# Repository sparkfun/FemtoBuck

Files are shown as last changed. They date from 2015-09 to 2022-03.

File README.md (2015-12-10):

FemtoBuck LED Driver
===================  
FemtoBuck LED Driver](https://cdn.sparkfun.com/assets/parts/1/1/2/1/0/13716-01.jpg) 
 
[*FemtoBuck LED Driver (COM-13716)*](https://www.sparkfun.com/products/13716) 

This breakout board allows you to dim a single high-power channel of LEDs from 0-330mA, or 0-660mA (depending on the setting of a solder jumper), at up to 36V. 
Dimming control can be either via PWM or via analog signal from 0-2.5V.

Repository Contents
-------------------
* **/Hardware** - All Eagle design files (.brd, .sch)
* **/Production** - Test bed files and production panel files

Documentation
--------------
* **[Hookup Guide](https://learn.sparkfun.com/tutorials/femtobuck-constant-current-led-driver-hookup-guide)** - Basic hookup guide for the FemtoBuck.
* **[SparkFun Fritzing repo](https://github.com/sparkfun/Fritzing_Parts)** - Fritzing diagrams for SparkFun products.
* **[SparkFun 3D Model repo](https://github.com/sparkfun/3D_Models)** - 3D models of SparkFun products. 

Product Versions
----------------
* [COM-13716](https://www.sparkfun.com/products/13716)- Version 1.2. Currently for sale. 
* [COM-12937] (https://www.sparkfun.com/products/12937)- Version 1.0. Retired. 

Version History
---------------
* [V_1.2](https://github.com/sparkfun/FemtoBuck/tree/V_1.2) - GitHub files for version 1.2. 
* [V_1.0](https://github.com/sparkfun/FemtoBuck/tree/v_10) - GitHub files for version 1.0. 

License Information
-------------------

This product is _**open source**_! 

Please review the LICENSE.md file for license information. 

If you have any questions or concerns on licensing, please contact techsupport@sparkfun.com.

Distributed as-is; no warranty is given.

- Your friends at SparkFun.

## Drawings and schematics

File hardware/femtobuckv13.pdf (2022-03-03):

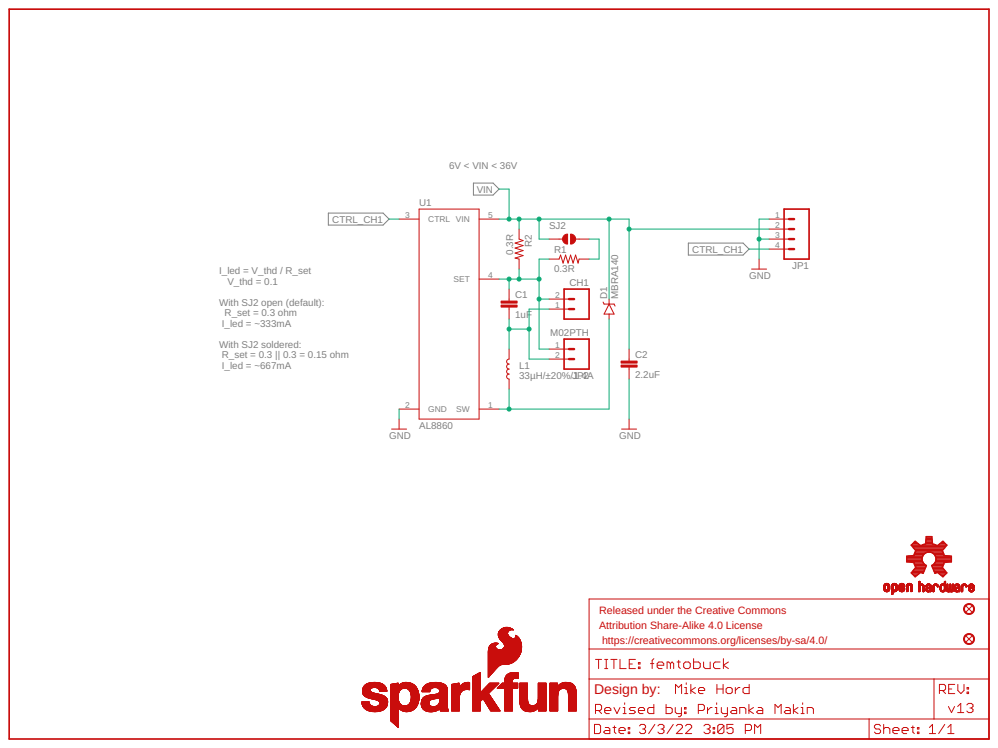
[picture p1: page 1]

Released under the Creative Commons Attribution Share-Alike 4.0 License

https://creativecommons.org/licenses/by-sa/4.0/

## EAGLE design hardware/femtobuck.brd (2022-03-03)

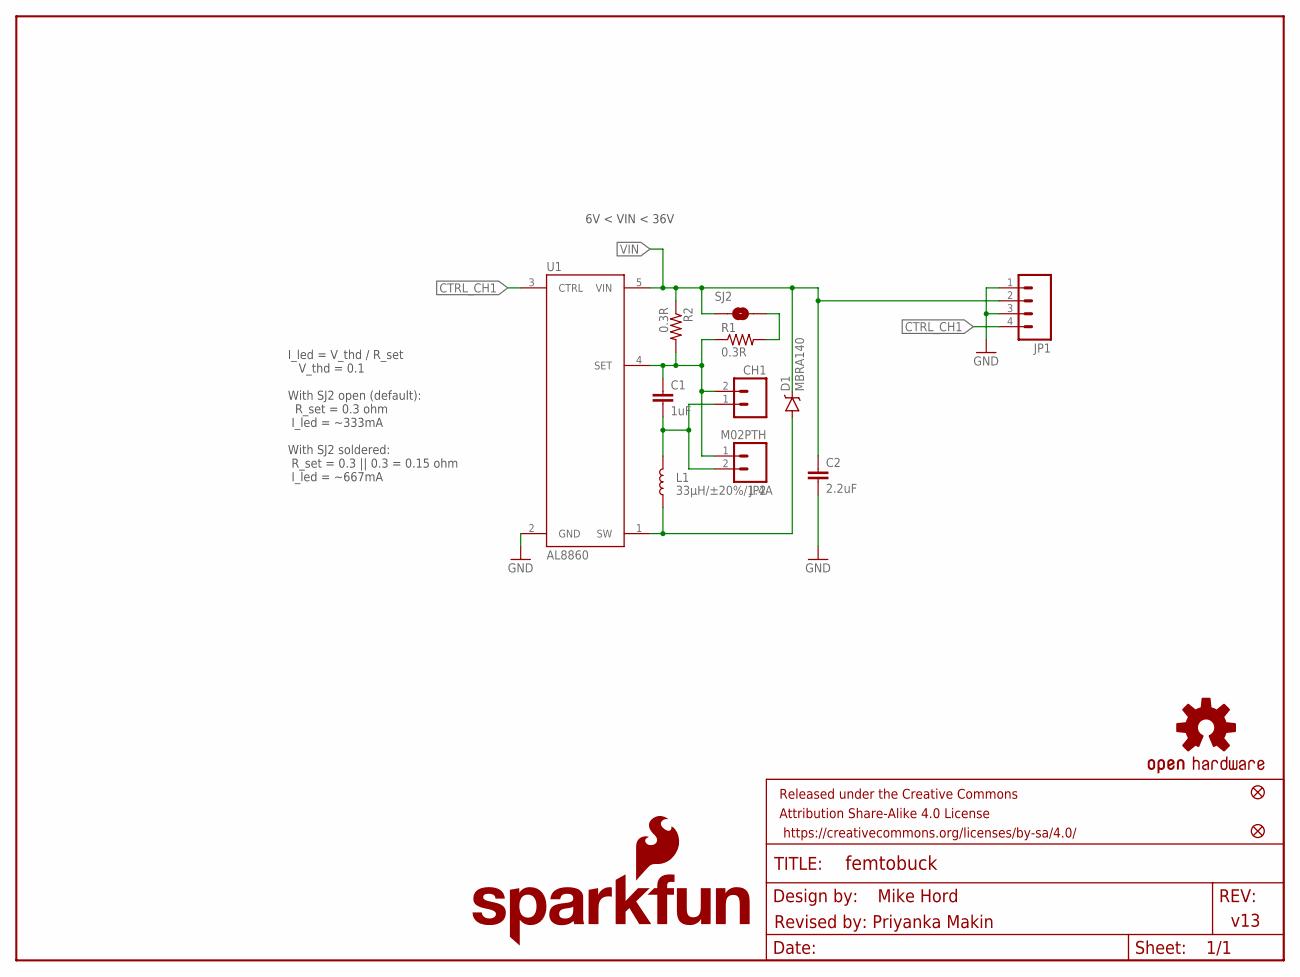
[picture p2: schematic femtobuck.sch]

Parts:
C1: 1uF; 1206-CAP
C2: 2.2uF; 1206-CAP
CH1: CONN_023.5MM_LOCK; SCREWTERMINAL-3.5MM-2_LOCK
D1: MBRA140; SMA-DIODE
FID1, FID2: FIDUCIAL1X2; FIDUCIAL-1X2
FRAME1: FRAME-LETTER; CREATIVE_COMMONS
JP1: M04PTH; 1X04
JP2: M02PTH; 1X02@1
L1: 33µH/±20%/1.4A; SRN6045
LOGO1: OSHW-LOGOS; OSHW-LOGO-S
LOGO2: SFE_LOGO_NAME_FLAME.1_INCH; SFE_LOGO_NAME_FLAME_.1
R1, R2: 0.3R; 0805
SJ2: NO Jumper; SMT-JUMPER_2_NO_NO-SILK
U1: AL8860; SOT23-5

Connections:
CTRL_CH1: JP1.4, U1.3 (CTRL)
GND: C2.2, JP1.1, JP1.3, U1.2 (GND)
unnamed: R1.2, SJ2.2
OUT+: C1.1, CH1.2, JP2.1, R1.1, R2.2, U1.4 (SET)
OUT-: C1.2, CH1.1, JP2.2, L1.2
SW: D1.A, L1.1, U1.1 (SW)
VIN: C2.1, D1.C, JP1.2, R2.1, SJ2.1, U1.5 (VIN)

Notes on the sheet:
I_led = V_thd / R_set V_thd = 0.1 With SJ2 open (default): R_set = 0.3 ohm I_led = ~333mA With SJ2 soldered: R_set = 0.3 || 0.3 = 0.15 ohm I_led = ~667mA
v13
Mike Hord
6V < VIN < 36V
Revised by: Priyanka Makin

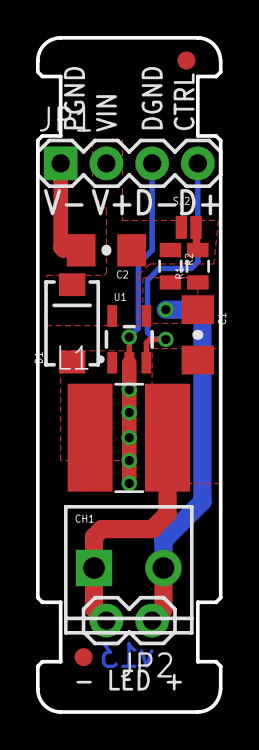
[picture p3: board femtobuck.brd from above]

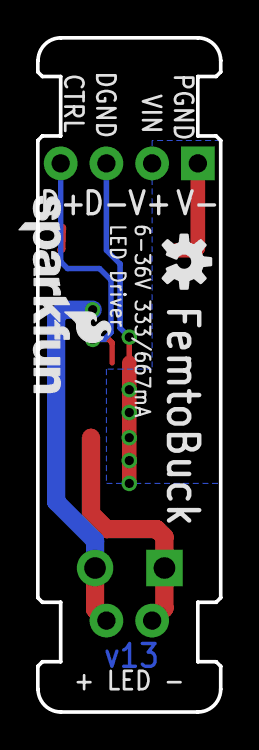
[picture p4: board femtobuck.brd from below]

Board: 2 copper layers, 10.2 x 37.5 mm, 16 parts (2 on the bottom side), 7 nets.

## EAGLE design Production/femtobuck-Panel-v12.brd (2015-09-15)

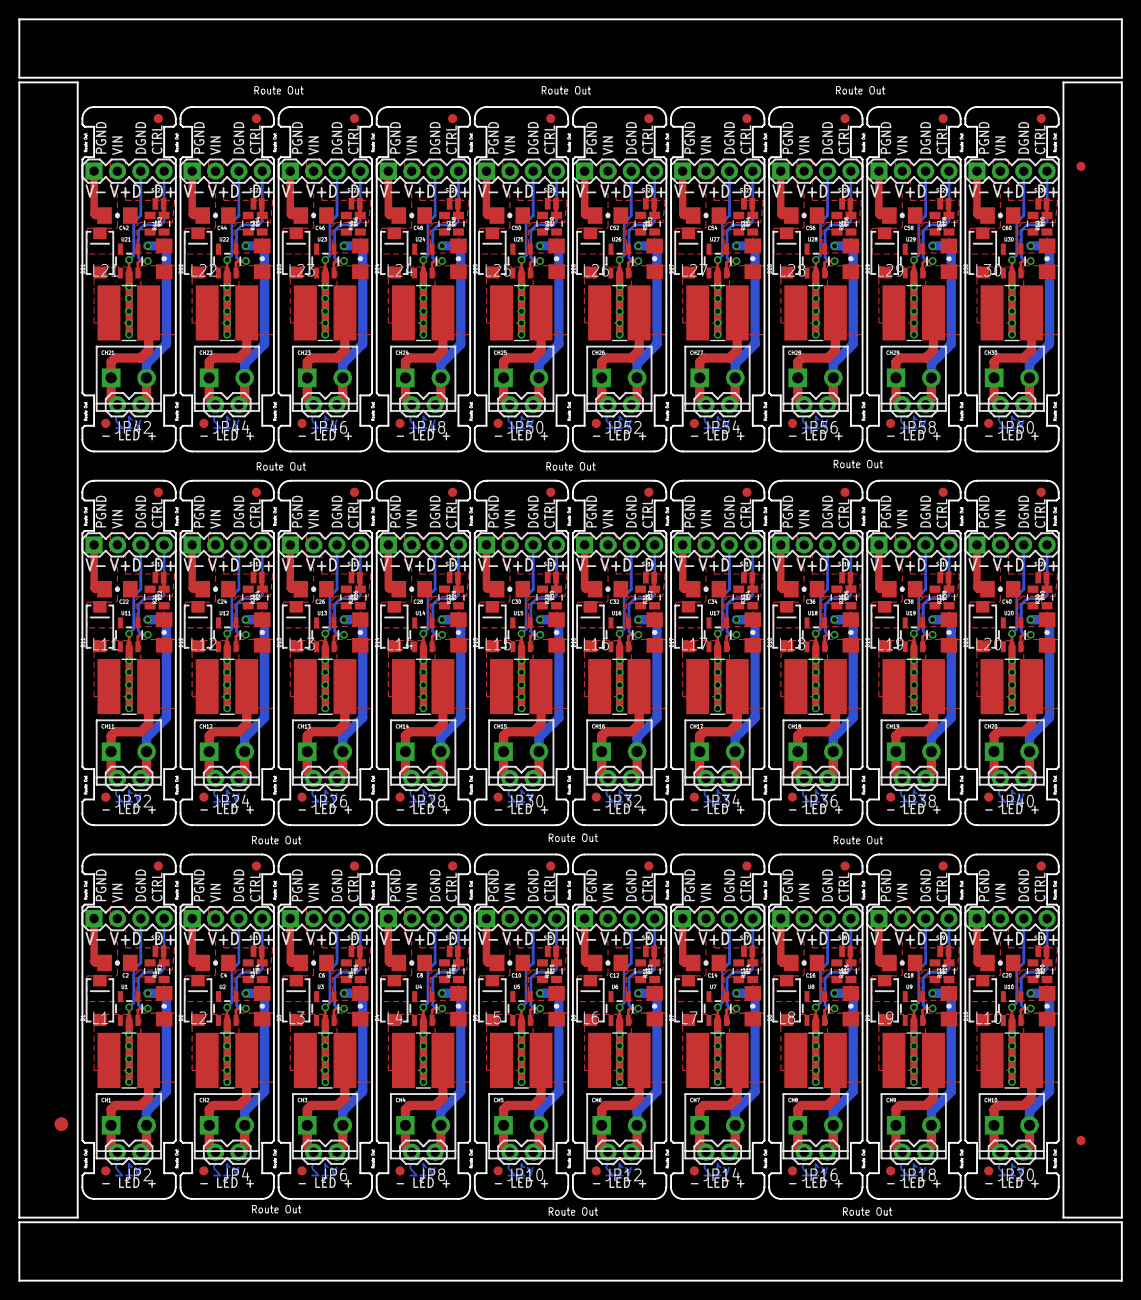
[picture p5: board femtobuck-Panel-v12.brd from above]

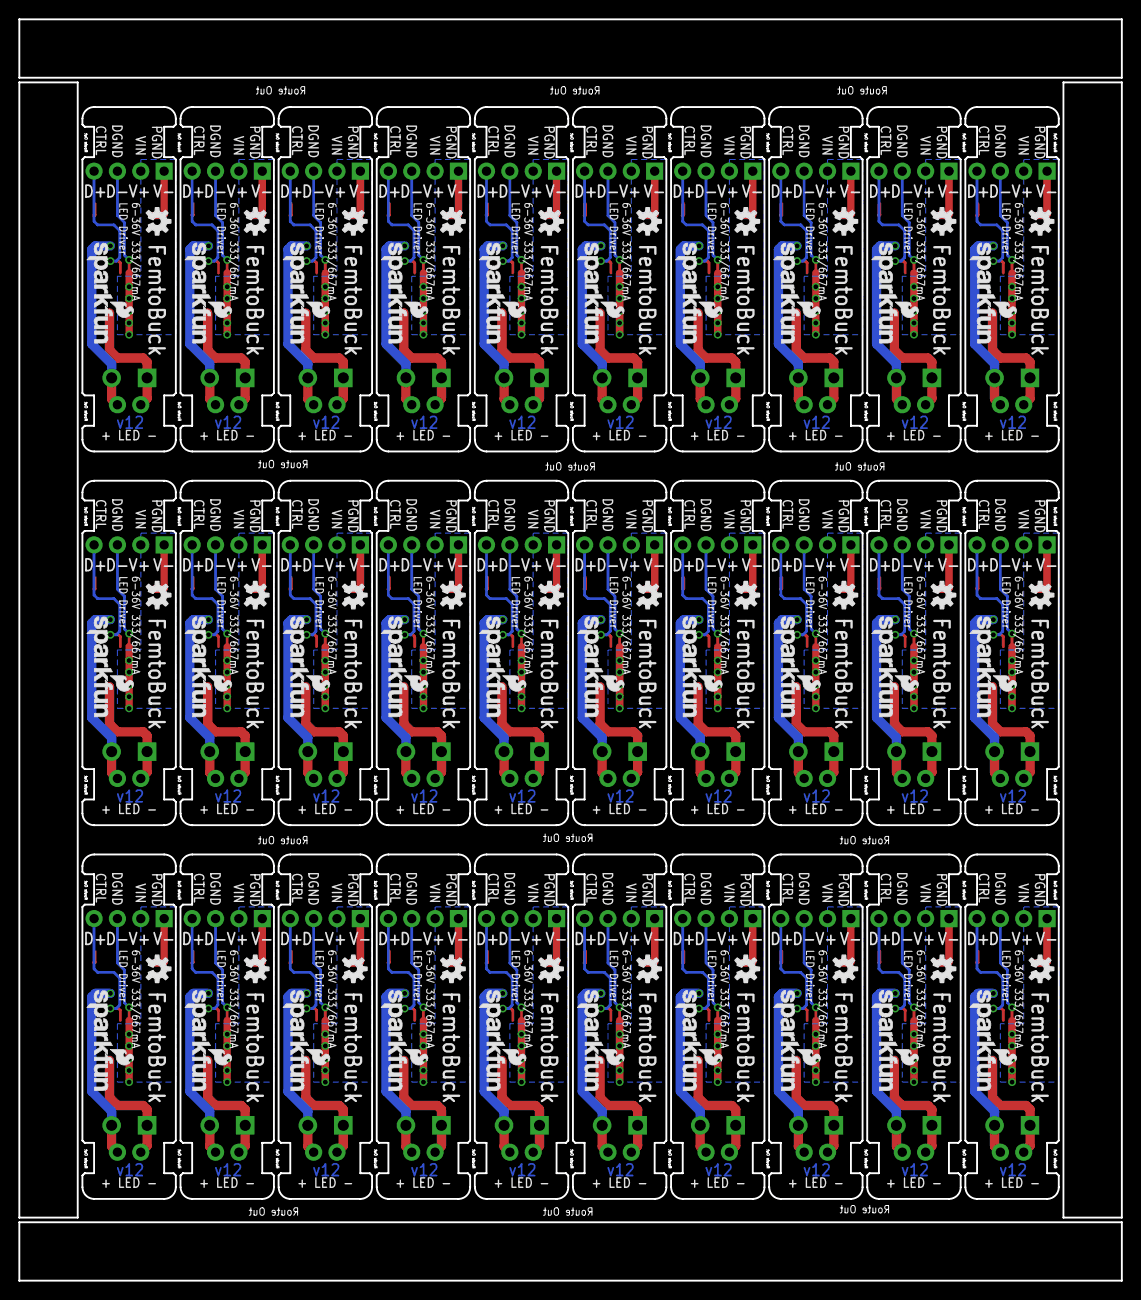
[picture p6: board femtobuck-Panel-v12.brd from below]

Board: 2 copper layers, 119.9 x 137.2 mm, 453 parts (60 on the bottom side), 210 nets.

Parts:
C1, C3, C5, C7, C9, C11, C13, C15, C17, C19, C21, C23, C25, C27, C29, C31, C33, C35, C37, C39, C41, C43, C45, C47, C49, C51, C53, C55, C57, C59: 1uF; 1206-CAP
C2, C4, C6, C8, C10, C12, C14, C16, C18, C20, C22, C24, C26, C28, C30, C32, C34, C36, C38, C40, C42, C44, C46, C48, C50, C52, C54, C56, C58, C60: 2.2uF; 1206-CAP
CH1, CH2, CH3, CH4, CH5, CH6, CH7, CH8, CH9, CH10, CH11, CH12, CH13, CH14, CH15, CH16, CH17, CH18, CH19, CH20, CH21, CH22, CH23, CH24, CH25, CH26, CH27, CH28, CH29, CH30: SCREWTERMINAL-3.5MM-2_LOCK
D1, D2, D3, D4, D5, D6, D7, D8, D9, D10, D11, D12, D13, D14, D15, D16, D17, D18, D19, D20, D21, D22, D23, D24, D25, D26, D27, D28, D29, D30: MBRA140; SMA-DIODE
E$1: FIDUCIAL-1.5X3
E$2, E$5: FIDUCIAL-1X2
FID1, FID2, FID3, FID4, FID5, FID6, FID7, FID8, FID9, FID10, FID11, FID12, FID13, FID14, FID15, FID16, FID17, FID18, FID19, FID20, FID21, FID22, FID23, FID24, FID25, FID26, FID27, FID28, FID29, FID30, FID31, FID32, FID33, FID34, FID35, FID36, FID37, FID38, FID39, FID40, FID41, FID42, FID43, FID44, FID45, FID46, FID47, FID48, FID49, FID50, FID51, FID52, FID53, FID54, FID55, FID56, FID57, FID58, FID59, FID60: FIDUCIAL1X2; FIDUCIAL-1X2
JP1, JP3, JP5, JP7, JP9, JP11, JP13, JP15, JP17, JP19, JP21, JP23, JP25, JP27, JP29, JP31, JP33, JP35, JP37, JP39, JP41, JP43, JP45, JP47, JP49, JP51, JP53, JP55, JP57, JP59: 1X04
JP2, JP4, JP6, JP8, JP10, JP12, JP14, JP16, JP18, JP20, JP22, JP24, JP26, JP28, JP30, JP32, JP34, JP36, JP38, JP40, JP42, JP44, JP46, JP48, JP50, JP52, JP54, JP56, JP58, JP60: M02PTH; 1X02
L1, L2, L3, L4, L5, L6, L7, L8, L9, L10, L11, L12, L13, L14, L15, L16, L17, L18, L19, L20, L21, L22, L23, L24, L25, L26, L27, L28, L29, L30: 33uH; SRN6045
LOGO1, LOGO3, LOGO5, LOGO7, LOGO9, LOGO11, LOGO13, LOGO15, LOGO17, LOGO19, LOGO21, LOGO23, LOGO25, LOGO27, LOGO29, LOGO31, LOGO33, LOGO35, LOGO37, LOGO39, LOGO41, LOGO43, LOGO45, LOGO47, LOGO49, LOGO51, LOGO53, LOGO55, LOGO57, LOGO59: OSHW-LOGOS; OSHW-LOGO-S
LOGO2, LOGO4, LOGO6, LOGO8, LOGO10, LOGO12, LOGO14, LOGO16, LOGO18, LOGO20, LOGO22, LOGO24, LOGO26, LOGO28, LOGO30, LOGO32, LOGO34, LOGO36, LOGO38, LOGO40, LOGO42, LOGO44, LOGO46, LOGO48, LOGO50, LOGO52, LOGO54, LOGO56, LOGO58, LOGO60: SFE_LOGO_NAME_FLAME.1_INCH; SFE_LOGO_NAME_FLAME_.1
R1, R2, R3, R4, R5, R6, R7, R8, R9, R10, R11, R12, R13, R14, R15, R16, R17, R18, R19, R20, R21, R22, R23, R24, R25, R26, R27, R28, R29, R30, R31, R32, R33, R34, R35, R36, R37, R38, R39, R40, R41, R42, R43, R44, R45, R46, R47, R48, R49, R50, R51, R52, R53, R54, R55, R56, R57, R58, R59, R60: 0.3R; 0805
SJ1, SJ2, SJ3, SJ4, SJ5, SJ6, SJ7, SJ8, SJ9, SJ10, SJ11, SJ12, SJ13, SJ14, SJ15, SJ16, SJ17, SJ18, SJ19, SJ20, SJ21, SJ22, SJ23, SJ24, SJ25, SJ26, SJ27, SJ28, SJ29, SJ30: NO Jumper; PAD-JUMPER-2-NO_NO_SILK
U1, U2, U3, U4, U5, U6, U7, U8, U9, U10, U11, U12, U13, U14, U15, U16, U17, U18, U19, U20, U21, U22, U23, U24, U25, U26, U27, U28, U29, U30: AL8805; SOT23-5

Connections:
CTRL_CH1: JP1.4, U1.3
CTRL_CH2: JP3.4, U2.3
CTRL_CH3: JP5.4, U3.3
CTRL_CH4: JP7.4, U4.3
CTRL_CH5: JP9.4, U5.3
CTRL_CH6: JP11.4, U6.3
CTRL_CH7: JP13.4, U7.3
CTRL_CH8: JP15.4, U8.3
CTRL_CH9: JP17.4, U9.3
CTRL_CH10: JP19.4, U10.3
CTRL_CH11: JP21.4, U11.3
CTRL_CH12: JP23.4, U12.3
CTRL_CH13: JP25.4, U13.3
CTRL_CH14: JP27.4, U14.3
CTRL_CH15: JP29.4, U15.3
CTRL_CH16: JP31.4, U16.3
CTRL_CH17: JP33.4, U17.3
CTRL_CH18: JP35.4, U18.3
CTRL_CH19: JP37.4, U19.3
CTRL_CH20: JP39.4, U20.3
CTRL_CH21: JP41.4, U21.3
CTRL_CH22: JP43.4, U22.3
CTRL_CH23: JP45.4, U23.3
CTRL_CH24: JP47.4, U24.3
CTRL_CH25: JP49.4, U25.3
CTRL_CH26: JP51.4, U26.3
CTRL_CH27: JP53.4, U27.3
CTRL_CH28: JP55.4, U28.3
CTRL_CH29: JP57.4, U29.3
CTRL_CH30: JP59.4, U30.3
GND: C2.2, JP1.1, JP1.3, U1.2
GND1: C4.2, JP3.1, JP3.3, U2.2
GND2: C6.2, JP5.1, JP5.3, U3.2
GND3: C8.2, JP7.1, JP7.3, U4.2
GND4: C10.2, JP9.1, JP9.3, U5.2
GND5: C12.2, JP11.1, JP11.3, U6.2
GND6: C14.2, JP13.1, JP13.3, U7.2
GND7: C16.2, JP15.1, JP15.3, U8.2
GND8: C18.2, JP17.1, JP17.3, U9.2
GND9: C20.2, JP19.1, JP19.3, U10.2
GND10: C22.2, JP21.1, JP21.3, U11.2
GND11: C24.2, JP23.1, JP23.3, U12.2
GND12: C26.2, JP25.1, JP25.3, U13.2
GND13: C28.2, JP27.1, JP27.3, U14.2
GND14: C30.2, JP29.1, JP29.3, U15.2
GND15: C32.2, JP31.1, JP31.3, U16.2
GND16: C34.2, JP33.1, JP33.3, U17.2
GND17: C36.2, JP35.1, JP35.3, U18.2
GND18: C38.2, JP37.1, JP37.3, U19.2
GND19: C40.2, JP39.1, JP39.3, U20.2
GND20: C42.2, JP41.1, JP41.3, U21.2
GND21: C44.2, JP43.1, JP43.3, U22.2
GND22: C46.2, JP45.1, JP45.3, U23.2
GND23: C48.2, JP47.1, JP47.3, U24.2
GND24: C50.2, JP49.1, JP49.3, U25.2
GND25: C52.2, JP51.1, JP51.3, U26.2
GND26: C54.2, JP53.1, JP53.3, U27.2
GND27: C56.2, JP55.1, JP55.3, U28.2
GND28: C58.2, JP57.1, JP57.3, U29.2
GND29: C60.2, JP59.1, JP59.3, U30.2
unnamed: R1.2, SJ2.2
unnamed: R3.2, SJ1.2
unnamed: R5.2, SJ3.2
unnamed: R7.2, SJ4.2
unnamed: R9.2, SJ5.2
unnamed: R11.2, SJ6.2
unnamed: R13.2, SJ7.2
unnamed: R15.2, SJ8.2
unnamed: R17.2, SJ9.2
unnamed: R19.2, SJ10.2
unnamed: R21.2, SJ11.2
unnamed: R23.2, SJ12.2
unnamed: R25.2, SJ13.2
unnamed: R27.2, SJ14.2
unnamed: R29.2, SJ15.2
unnamed: R31.2, SJ16.2
unnamed: R33.2, SJ17.2
unnamed: R35.2, SJ18.2
unnamed: R37.2, SJ19.2
unnamed: R39.2, SJ20.2
unnamed: R41.2, SJ21.2
unnamed: R43.2, SJ22.2
unnamed: R45.2, SJ23.2
unnamed: R47.2, SJ24.2
unnamed: R49.2, SJ25.2
unnamed: R51.2, SJ26.2
unnamed: R53.2, SJ27.2
unnamed: R55.2, SJ28.2
unnamed: R57.2, SJ29.2
unnamed: R59.2, SJ30.2
OUT+: C1.1, CH1.2, JP2.1, R1.1, R2.2, U1.4
OUT+1: C3.1, CH2.2, JP4.1, R3.1, R4.2, U2.4
OUT+2: C5.1, CH3.2, JP6.1, R5.1, R6.2, U3.4
OUT+3: C7.1, CH4.2, JP8.1, R7.1, R8.2, U4.4
OUT+4: C9.1, CH5.2, JP10.1, R9.1, R10.2, U5.4
OUT+5: C11.1, CH6.2, JP12.1, R11.1, R12.2, U6.4
OUT+6: C13.1, CH7.2, JP14.1, R13.1, R14.2, U7.4
OUT+7: C15.1, CH8.2, JP16.1, R15.1, R16.2, U8.4
OUT+8: C17.1, CH9.2, JP18.1, R17.1, R18.2, U9.4
OUT+9: C19.1, CH10.2, JP20.1, R19.1, R20.2, U10.4
OUT+10: C21.1, CH11.2, JP22.1, R21.1, R22.2, U11.4
OUT+11: C23.1, CH12.2, JP24.1, R23.1, R24.2, U12.4
OUT+12: C25.1, CH13.2, JP26.1, R25.1, R26.2, U13.4
OUT+13: C27.1, CH14.2, JP28.1, R27.1, R28.2, U14.4
OUT+14: C29.1, CH15.2, JP30.1, R29.1, R30.2, U15.4
OUT+15: C31.1, CH16.2, JP32.1, R31.1, R32.2, U16.4
OUT+16: C33.1, CH17.2, JP34.1, R33.1, R34.2, U17.4
OUT+17: C35.1, CH18.2, JP36.1, R35.1, R36.2, U18.4
OUT+18: C37.1, CH19.2, JP38.1, R37.1, R38.2, U19.4
OUT+19: C39.1, CH20.2, JP40.1, R39.1, R40.2, U20.4
OUT+20: C41.1, CH21.2, JP42.1, R41.1, R42.2, U21.4
OUT+21: C43.1, CH22.2, JP44.1, R43.1, R44.2, U22.4
OUT+22: C45.1, CH23.2, JP46.1, R45.1, R46.2, U23.4
OUT+23: C47.1, CH24.2, JP48.1, R47.1, R48.2, U24.4
OUT+24: C49.1, CH25.2, JP50.1, R49.1, R50.2, U25.4
OUT+25: C51.1, CH26.2, JP52.1, R51.1, R52.2, U26.4
OUT+26: C53.1, CH27.2, JP54.1, R53.1, R54.2, U27.4
OUT+27: C55.1, CH28.2, JP56.1, R55.1, R56.2, U28.4
OUT+28: C57.1, CH29.2, JP58.1, R57.1, R58.2, U29.4
OUT+29: C59.1, CH30.2, JP60.1, R59.1, R60.2, U30.4
OUT-: C1.2, CH1.1, JP2.2, L1.2
OUT-1: C3.2, CH2.1, JP4.2, L2.2
OUT-2: C5.2, CH3.1, JP6.2, L3.2
OUT-3: C7.2, CH4.1, JP8.2, L4.2
OUT-4: C9.2, CH5.1, JP10.2, L5.2
OUT-5: C11.2, CH6.1, JP12.2, L6.2
OUT-6: C13.2, CH7.1, JP14.2, L7.2
OUT-7: C15.2, CH8.1, JP16.2, L8.2
OUT-8: C17.2, CH9.1, JP18.2, L9.2
OUT-9: C19.2, CH10.1, JP20.2, L10.2
OUT-10: C21.2, CH11.1, JP22.2, L11.2
OUT-11: C23.2, CH12.1, JP24.2, L12.2
OUT-12: C25.2, CH13.1, JP26.2, L13.2
OUT-13: C27.2, CH14.1, JP28.2, L14.2
OUT-14: C29.2, CH15.1, JP30.2, L15.2
OUT-15: C31.2, CH16.1, JP32.2, L16.2
OUT-16: C33.2, CH17.1, JP34.2, L17.2
OUT-17: C35.2, CH18.1, JP36.2, L18.2
OUT-18: C37.2, CH19.1, JP38.2, L19.2
OUT-19: C39.2, CH20.1, JP40.2, L20.2
OUT-20: C41.2, CH21.1, JP42.2, L21.2
OUT-21: C43.2, CH22.1, JP44.2, L22.2
OUT-22: C45.2, CH23.1, JP46.2, L23.2
OUT-23: C47.2, CH24.1, JP48.2, L24.2
OUT-24: C49.2, CH25.1, JP50.2, L25.2
OUT-25: C51.2, CH26.1, JP52.2, L26.2
OUT-26: C53.2, CH27.1, JP54.2, L27.2
OUT-27: C55.2, CH28.1, JP56.2, L28.2
OUT-28: C57.2, CH29.1, JP58.2, L29.2
OUT-29: C59.2, CH30.1, JP60.2, L30.2
SW: D1.A, L1.1, U1.1
SW1: D2.A, L2.1, U2.1
SW2: D3.A, L3.1, U3.1
SW3: D4.A, L4.1, U4.1
SW4: D5.A, L5.1, U5.1
SW5: D6.A, L6.1, U6.1
SW6: D7.A, L7.1, U7.1
SW7: D8.A, L8.1, U8.1
SW8: D9.A, L9.1, U9.1
SW9: D10.A, L10.1, U10.1
SW10: D11.A, L11.1, U11.1
SW11: D12.A, L12.1, U12.1
SW12: D13.A, L13.1, U13.1
SW13: D14.A, L14.1, U14.1
SW14: D15.A, L15.1, U15.1
SW15: D16.A, L16.1, U16.1
SW16: D17.A, L17.1, U17.1
SW17: D18.A, L18.1, U18.1
SW18: D19.A, L19.1, U19.1
SW19: D20.A, L20.1, U20.1
SW20: D21.A, L21.1, U21.1
SW21: D22.A, L22.1, U22.1
SW22: D23.A, L23.1, U23.1
SW23: D24.A, L24.1, U24.1
SW24: D25.A, L25.1, U25.1
SW25: D26.A, L26.1, U26.1
SW26: D27.A, L27.1, U27.1
SW27: D28.A, L28.1, U28.1
SW28: D29.A, L29.1, U29.1
SW29: D30.A, L30.1, U30.1
VIN: C2.1, D1.C, JP1.2, R2.1, SJ2.1, U1.5
VIN1: C4.1, D2.C, JP3.2, R4.1, SJ1.1, U2.5
VIN2: C6.1, D3.C, JP5.2, R6.1, SJ3.1, U3.5
VIN3: C8.1, D4.C, JP7.2, R8.1, SJ4.1, U4.5
VIN4: C10.1, D5.C, JP9.2, R10.1, SJ5.1, U5.5
VIN5: C12.1, D6.C, JP11.2, R12.1, SJ6.1, U6.5
VIN6: C14.1, D7.C, JP13.2, R14.1, SJ7.1, U7.5
VIN7: C16.1, D8.C, JP15.2, R16.1, SJ8.1, U8.5
VIN8: C18.1, D9.C, JP17.2, R18.1, SJ9.1, U9.5
VIN9: C20.1, D10.C, JP19.2, R20.1, SJ10.1, U10.5
VIN10: C22.1, D11.C, JP21.2, R22.1, SJ11.1, U11.5
VIN11: C24.1, D12.C, JP23.2, R24.1, SJ12.1, U12.5
VIN12: C26.1, D13.C, JP25.2, R26.1, SJ13.1, U13.5
VIN13: C28.1, D14.C, JP27.2, R28.1, SJ14.1, U14.5
VIN14: C30.1, D15.C, JP29.2, R30.1, SJ15.1, U15.5
VIN15: C32.1, D16.C, JP31.2, R32.1, SJ16.1, U16.5
VIN16: C34.1, D17.C, JP33.2, R34.1, SJ17.1, U17.5
VIN17: C36.1, D18.C, JP35.2, R36.1, SJ18.1, U18.5
VIN18: C38.1, D19.C, JP37.2, R38.1, SJ19.1, U19.5
VIN19: C40.1, D20.C, JP39.2, R40.1, SJ20.1, U20.5
VIN20: C42.1, D21.C, JP41.2, R42.1, SJ21.1, U21.5
VIN21: C44.1, D22.C, JP43.2, R44.1, SJ22.1, U22.5
VIN22: C46.1, D23.C, JP45.2, R46.1, SJ23.1, U23.5
VIN23: C48.1, D24.C, JP47.2, R48.1, SJ24.1, U24.5
VIN24: C50.1, D25.C, JP49.2, R50.1, SJ25.1, U25.5
VIN25: C52.1, D26.C, JP51.2, R52.1, SJ26.1, U26.5
VIN26: C54.1, D27.C, JP53.2, R54.1, SJ27.1, U27.5
VIN27: C56.1, D28.C, JP55.2, R56.1, SJ28.1, U28.5
VIN28: C58.1, D29.C, JP57.2, R58.1, SJ29.1, U29.5
VIN29: C60.1, D30.C, JP59.2, R60.1, SJ30.1, U30.5

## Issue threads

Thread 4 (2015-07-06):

v11 Checklist Issues

ericorosel, 2015-07-06:
If the board's size or form is causing or the reason for any of the issues mentioned below, and said issue cannot be resolved without disrupting the size or form; just mention that. I understand that the size/form of this board is an important selling point.

(1) U1 needs a value. I think "AL8805" would do.

(2) The left side of the current-set jumper is really close to the resistor pad below. If we could move this up even a little I think we would be saving ourselves some trouble on the manufacturing side.

(3) Looks like the bottom-side GND trace has some funny angles (other than 45 degrees)

(4) "OUT-" trace is entering the inductor pad at an angle

(5) Got an airwire on "CTRL_CH1"

(6) Need measures

(7) R1, R2, C1, C2 and L1 all need silk (TPlace) for footprints

(8) It would be nice to have a label for the current-set jumper. Maybe a note on the bottom of the board after the "6-36V 333/667mA" eg: "6-36V 333/667mA (OPEN/CLOSED)" Just a thought.

That's it.

mhord, 2015-07-07:
1. Fixed.
2. Scooted up 0.005". That's getting dangerously close to the silk above it.
3. Oops. Fixed.
4. Fixed.
5. Fixed.
6. Fixed.
7. R1 and R2 had silk (?), fixed others in library.
8. It would be nice, but I think it would leave the board hopelessly crowded.

Closed 2015-07-07.

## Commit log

2014-05-19 Incorporate changes from review
    [femtobuck.brd, femtobuck.sch]
2014-06-18 Small updates for production
    [femtobuck.brd, femtobuck.sch]
2014-06-19 added board fiducials
    [femtobuck.brd, femtobuck.sch]
2014-06-19 created panel v10
    [femtobuck-Panel-v10.brd]
2015-07-01 Added 2nd sense resistor, jumper
    [femtobuck.brd, femtobuck.sch]
2015-07-07 Fixed changes from QC
    [femtobuck.brd, femtobuck.sch]
2015-08-10 created panel v11
    [femtobuck-Panel-v10.brd, femtobuck-Panel-v11.brd]
2015-08-11 Chg to 12, inc. line wid on logos
    [femtobuck.brd, femtobuck.sch]
2015-08-12 created panel v12
    [femtobuck-Panel-v11.brd, femtobuck-Panel-v12.brd]
2022-03-03 AL8805 Buck LED driver EOL, replace with AL8860
    [femtobuck.brd, femtobuck.sch]

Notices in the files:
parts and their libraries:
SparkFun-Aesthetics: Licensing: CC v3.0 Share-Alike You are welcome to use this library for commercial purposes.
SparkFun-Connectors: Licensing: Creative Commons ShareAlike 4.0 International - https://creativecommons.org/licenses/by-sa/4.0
